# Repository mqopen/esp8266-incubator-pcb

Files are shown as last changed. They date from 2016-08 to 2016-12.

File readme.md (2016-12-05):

# ESP8266 Incubator PCB
Design of ESP8266 incubator PCB.

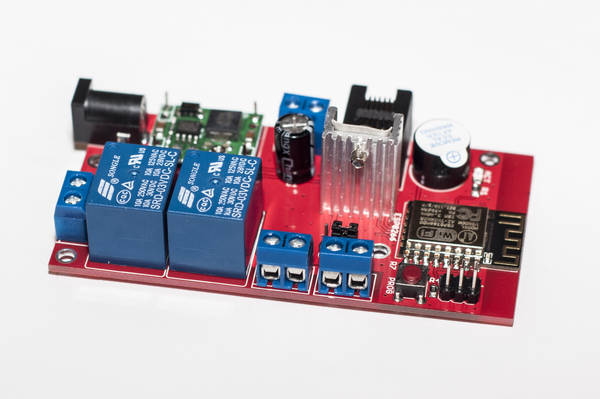
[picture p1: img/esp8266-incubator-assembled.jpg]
Assembled incubator


## Features

  * Powered by mini DC-DC power supply module ([LM2596](http://www.ti.com/lit/ds/symlink/lm2596.pdf) chip).
  * 5.5 mm center positive jack.
  * On-board programming connector.
  * Programming push button.
  * Jumper for enabling power supply module.
  * RJ-11 connector for connecting various sensors.
  * Notification LED.
  * Intended to be manufactured by [dirtypcbs.com](http://dirtypcbs.com/).
  * AVR like ISP header for in circuit programming.
  * Two relays in series for driving heater circuit.
  * Two screw terminals for connecting heaters.
  * 12V screw terminal for controlling fan.
  * Piezo buzzer for alarm signaling.

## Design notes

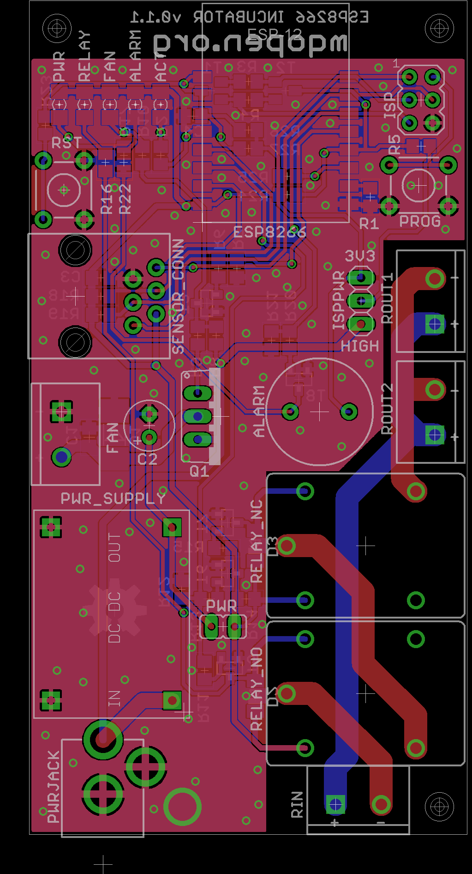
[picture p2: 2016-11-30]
img/board.png

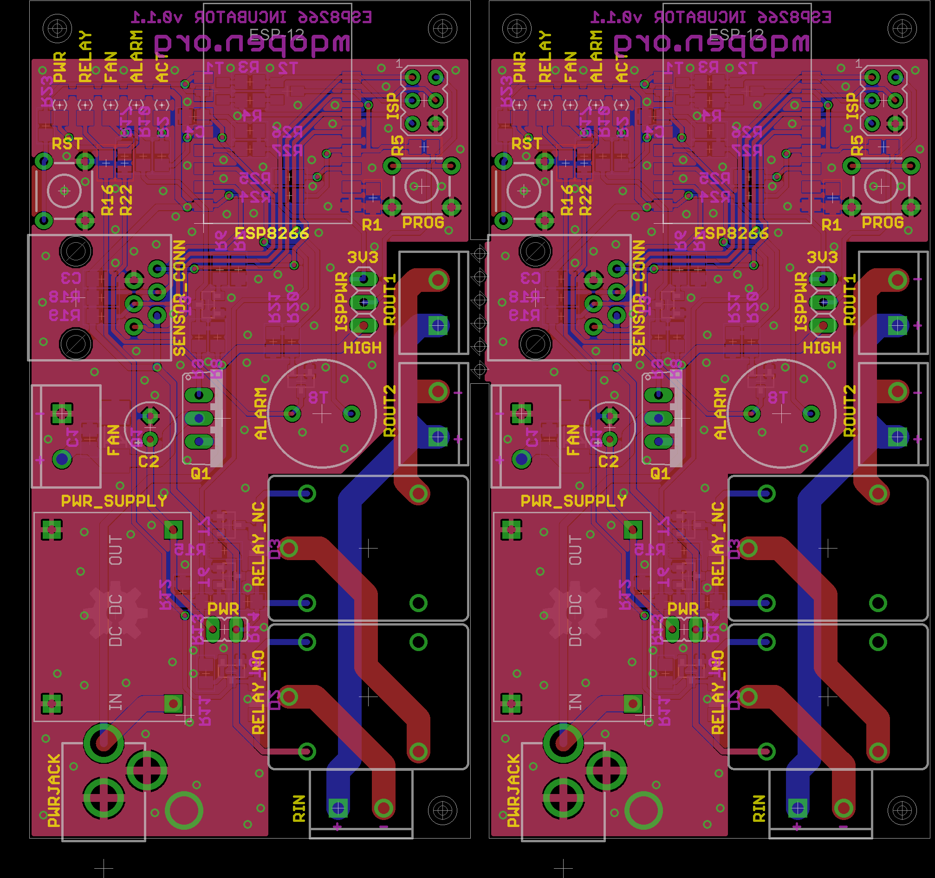
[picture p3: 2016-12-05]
img/board_panelized.png

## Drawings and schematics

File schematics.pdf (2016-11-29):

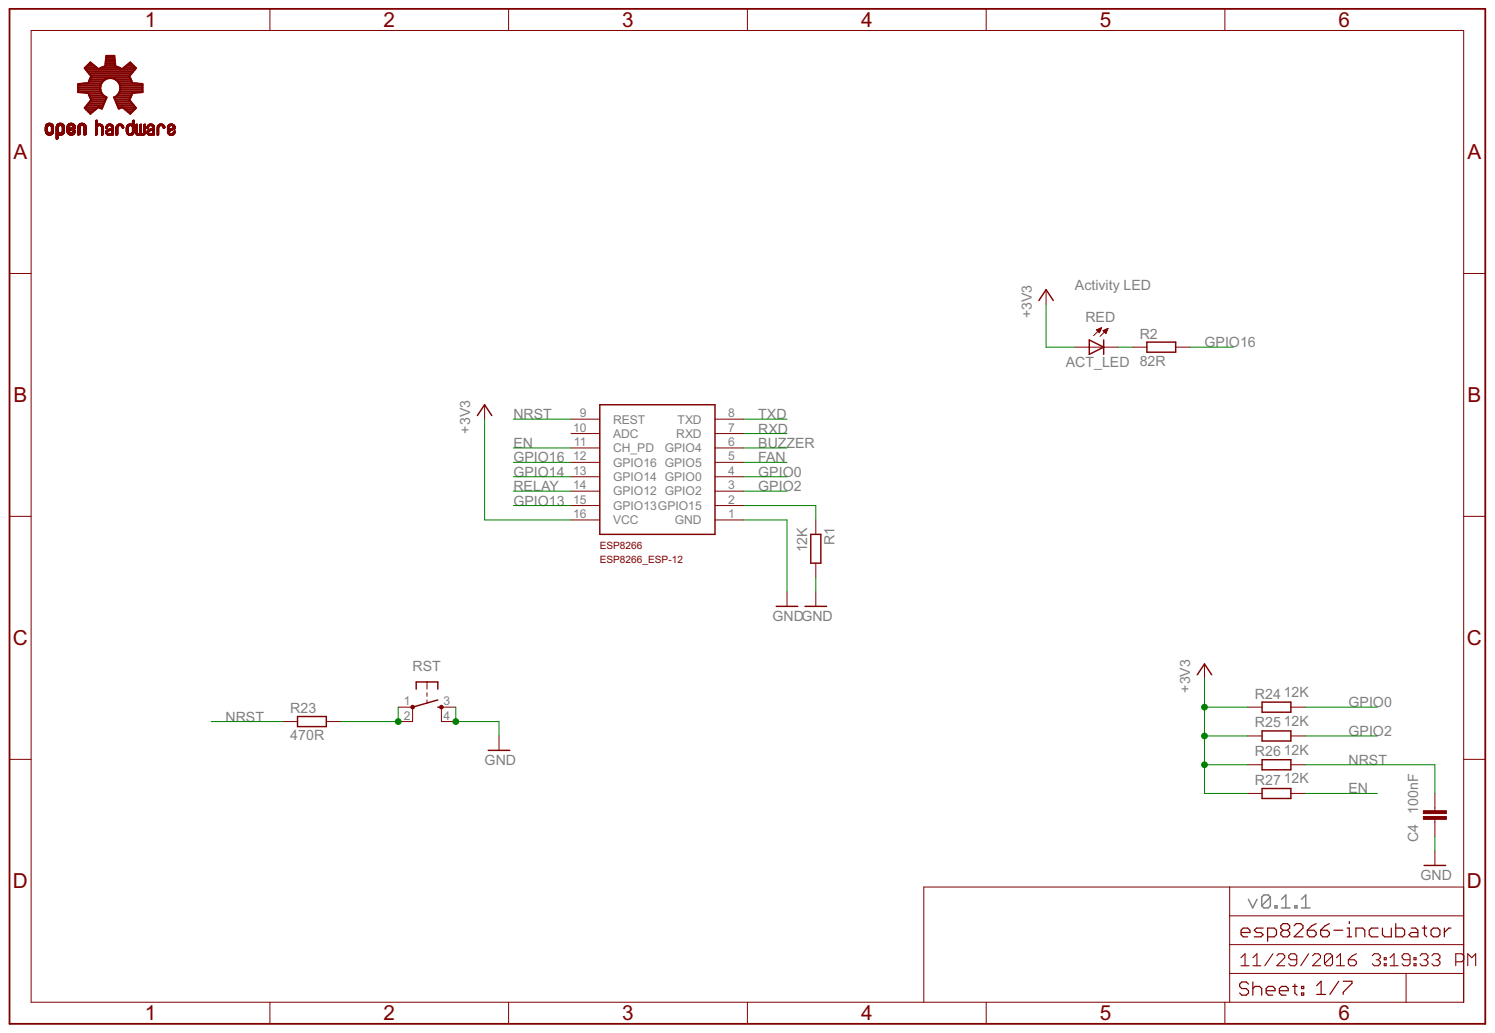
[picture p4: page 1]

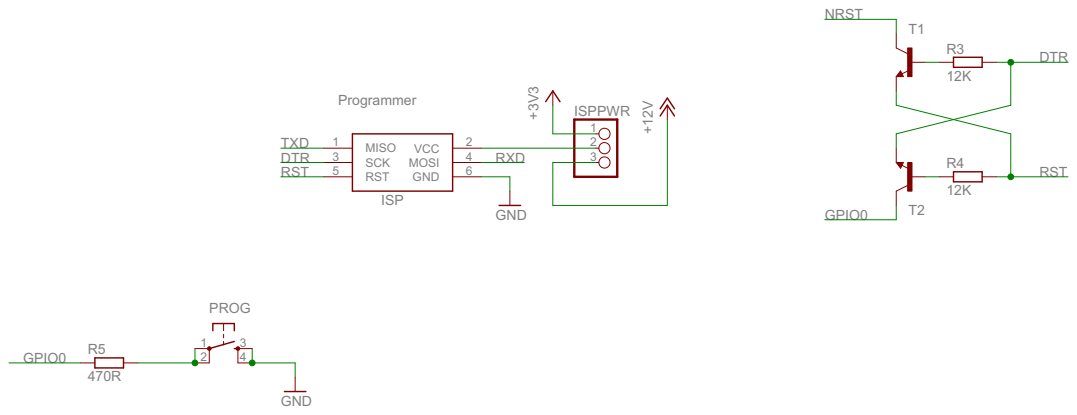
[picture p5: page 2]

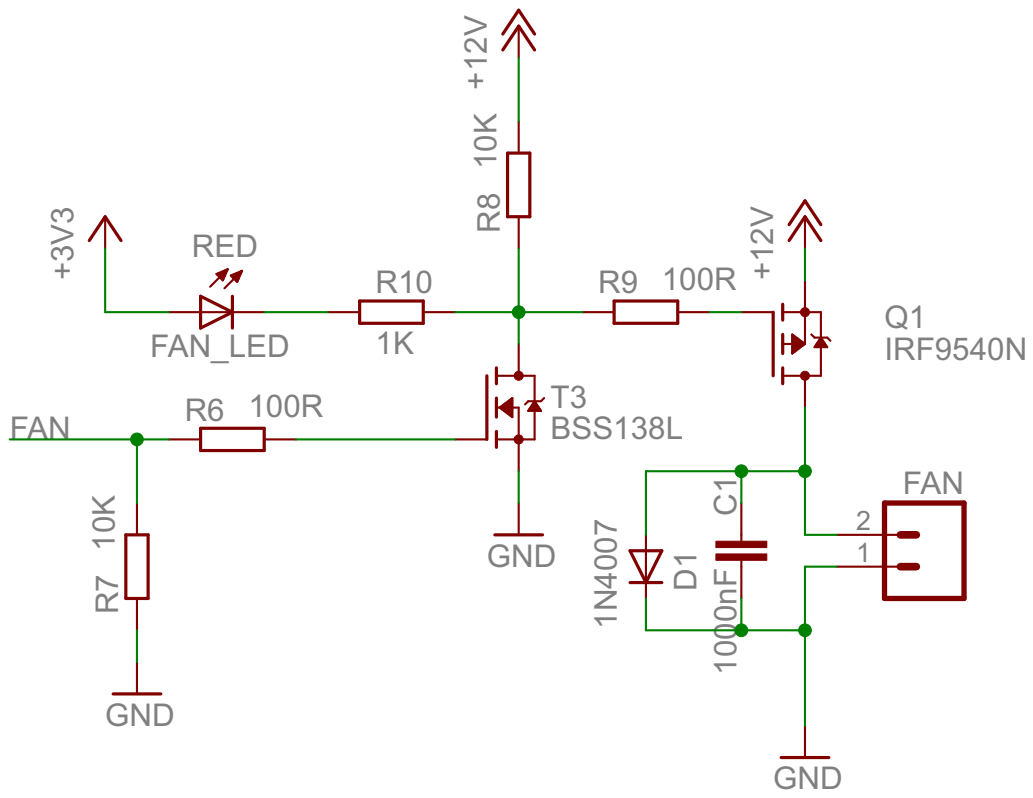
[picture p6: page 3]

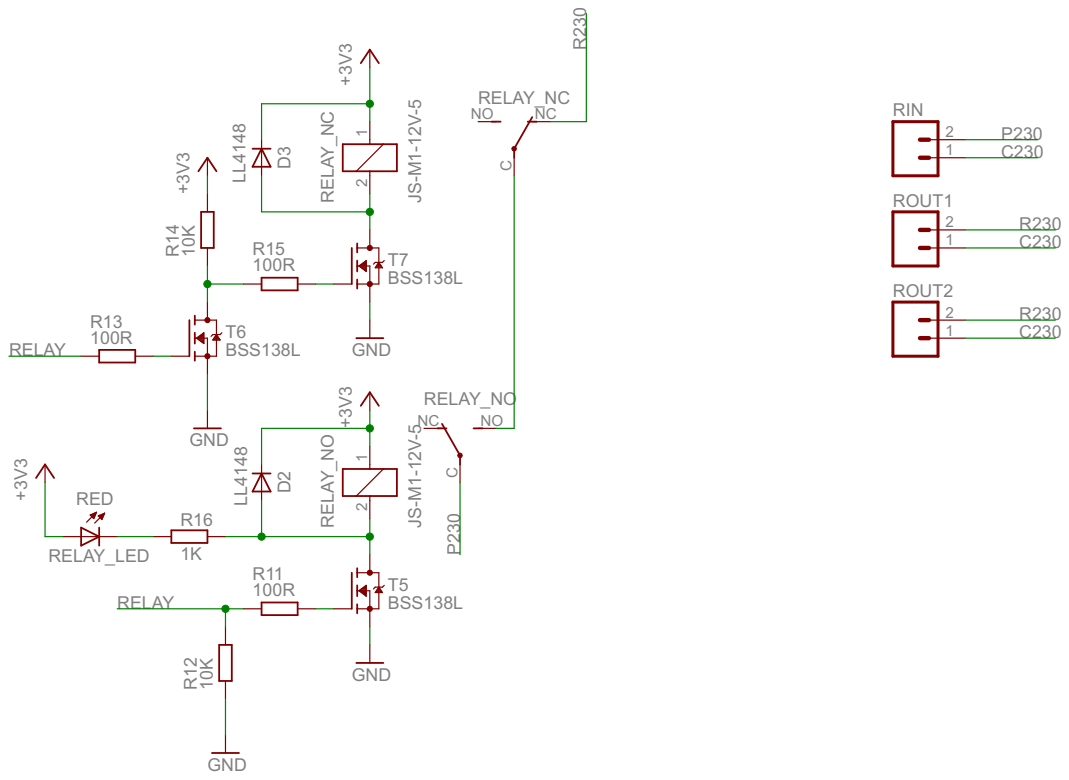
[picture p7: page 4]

JS-M1-12V-5 JS-M1-12V-5 LL4148 LL4148 100R +3V3 GND 100R 100R GND 10K +3V3 GNDBSS138L 10K GNDBSS138L BSS138L +3V3 RED 1K +3V3 2 1 RELAY_NCNO NC C RELAY_NC 2 1 RELAY_NO NC NO C RELAY_NO D2 D3 R13 R15 R11 R14 T5 R12 T6 T7 RELAY_LED R16 RIN 12 ROUT112 ROUT212 R230 R230 R230 P230 P230 RELAY RELAY C230 C230 C230 ABCD 1 2 3 4 5 6 ABCD 1 2 3 4 5 6

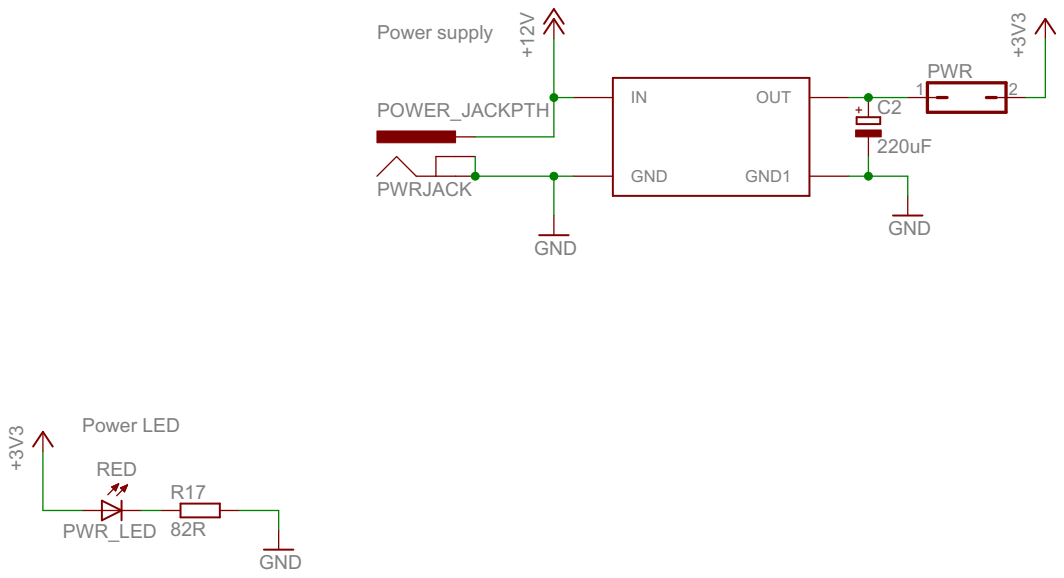
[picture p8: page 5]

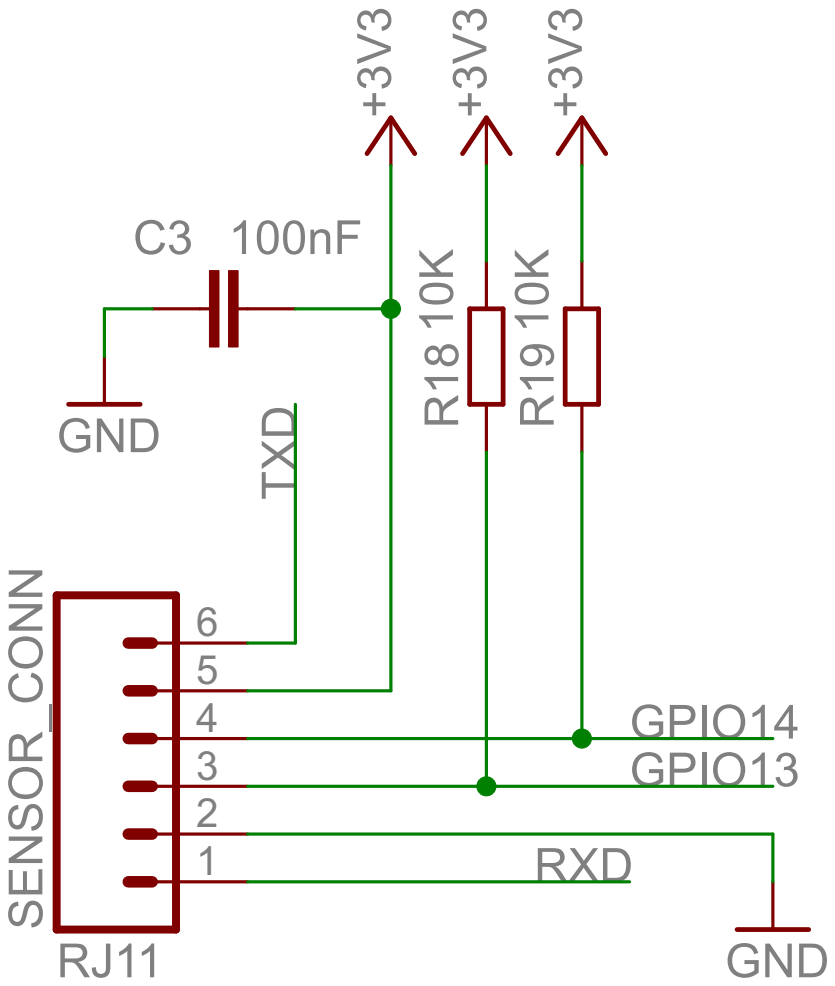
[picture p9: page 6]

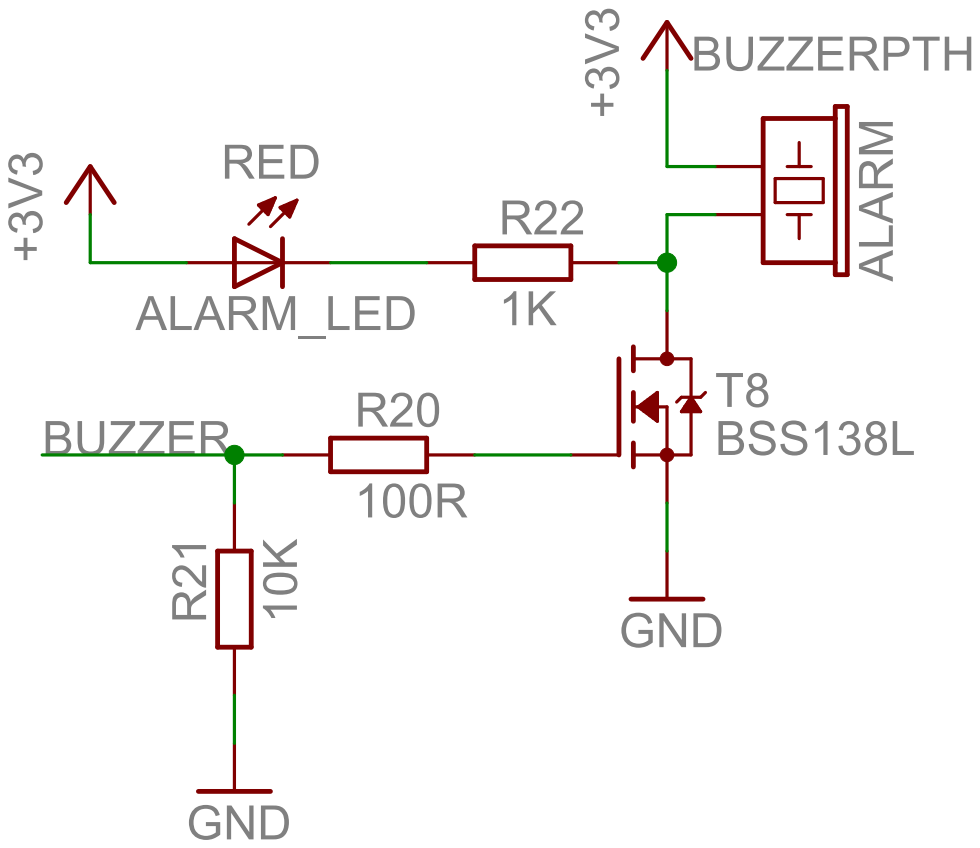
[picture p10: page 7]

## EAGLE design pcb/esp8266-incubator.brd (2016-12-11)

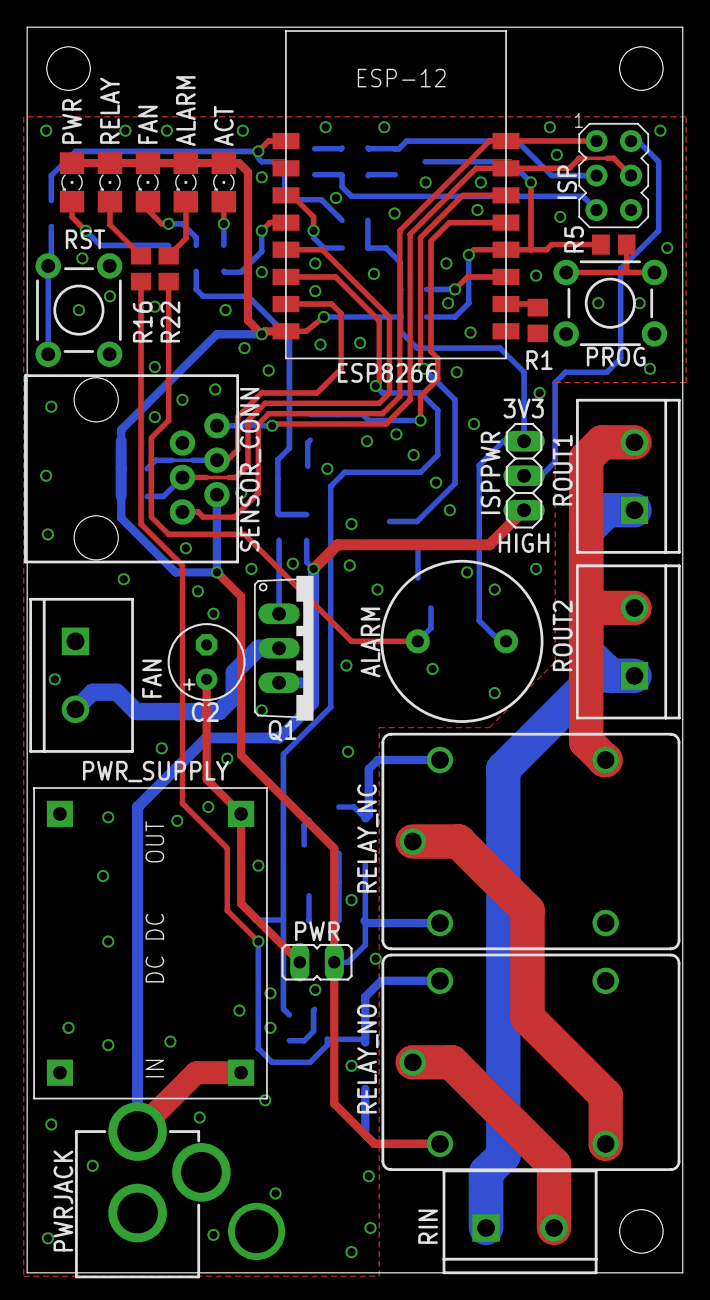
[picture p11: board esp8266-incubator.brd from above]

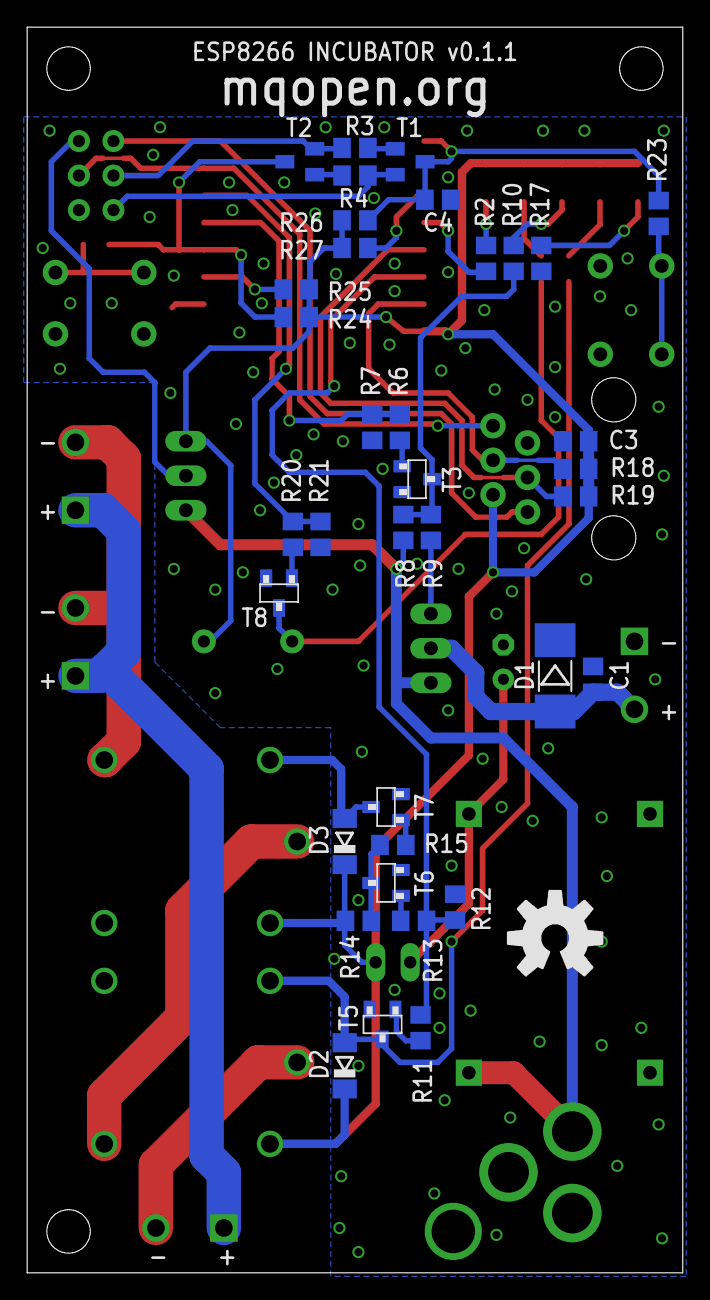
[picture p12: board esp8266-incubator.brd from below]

Board: 2 copper layers, 48.3 x 91.7 mm, 64 parts (37 on the bottom side), 45 nets.

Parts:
ACT_LED: RED; 1206
ALARM: BUZZERPTH; BUZZER-12MM
ALARM_LED: RED; 1206
C1: 1000nF; C0805
C2: 220uF; E2,5-6
C3, C4: 100nF; C0805
D1: 1N4007; MELF-MLL41
D2, D3: LL4148; SOD80C
ESP8266: ESP8266_ESP-12; ESP8266-ESP12
FAN: SCREWTERMINAL-5MM-2
FAN_LED: RED; 1206
ISP: AVRISP-6; AVRISP
ISPPWR: 1X03
PROG: TACTILE-PTH
PWR: JP1
PWRJACK: POWER_JACKPTH; POWER_JACK_PTH
PWR_LED: RED; 1206
PWR_SUPPLY: DC-DC-SMALL; DC-DC
Q1: IRF9540N; TO220V
R1, R3, R4, R7, R8, R12, R14, R18, R19, R21, R24, R25, R26, R27: 10K; R0805
R2, R17: 82R; R0805
R5, R23: 470R; R0805
R6, R9, R11, R13, R15, R20: 100R; R0805
R10, R16, R22: 1K; R0805
RELAY_LED: RED; 1206
RELAY_NC: JS-M1-12V-5; JS-M
RELAY_NO: JS-M1-12V-5; JS-M
RIN: SCREWTERMINAL-5MM-2
ROUT1, ROUT2: SCREWTERMINAL-5MM-2
RST: TACTILE-PTH
SENSOR_CONN: RJ11; RJ11-6
T1, T2: S8050; SOT23-BEC
T3, T5, T6, T7, T8: BSS138L; SOT23
U$1000: OSHW-LOGOL; OSHW-LOGO-L

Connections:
+3V3: ACT_LED.A, ALARM.+, ALARM_LED.A, C3.2, D2.C, D3.C, ESP8266.16, FAN_LED.A, ISPPWR.1, PWR.2, PWR_LED.A, R14.1, R18.2, R19.2, R24.2, R25.2, R26.2, R27.2, RELAY_LED.A, RELAY_NC.1, RELAY_NO.1, SENSOR_CONN.5
+12V: ISPPWR.3, PWRJACK.PWR, PWR_SUPPLY.P$1, Q1.3, R8.1
BUZZER: ESP8266.6, R20.2, R21.1
C230: RIN.1, ROUT1.1, ROUT2.1
DTR: ISP.3, R3.2, T2.E
EN: ESP8266.11, R27.1
FAN: ESP8266.5, R6.2, R7.1
GND: C1.1, C2.-, C3.1, C4.1, D1.C, ESP8266.1, FAN.1, ISP.6, PROG.3, PROG.4, PWRJACK.GND, PWRJACK.GNDBREAK, PWR_SUPPLY.P$3, PWR_SUPPLY.P$4, R1.2, R7.2, R12.2, R17.2, R21.2, RST.3, RST.4, SENSOR_CONN.2, T3.2, T5.2, T6.2, T7.2, T8.2
GPIO0: ESP8266.4, R5.1, R24.1, T2.C
GPIO2: ESP8266.3, R25.1
GPIO13: ESP8266.15, R18.1, SENSOR_CONN.3
GPIO14: ESP8266.13, R19.1, SENSOR_CONN.4
GPIO16: ESP8266.12, R2.2
unnamed: ACT_LED.C, R2.1
unnamed: C2.+, PWR.1, PWR_SUPPLY.P$2
unnamed: R3.1, T1.B
unnamed: PROG.1, PROG.2, R5.2
unnamed: ESP8266.2, R1.1
unnamed: ISP.2, ISPPWR.2
unnamed: R4.1, T2.B
unnamed: R20.1, T8.1
unnamed: D2.A, R16.2, RELAY_NO.2, T5.3
unnamed: R11.1, T5.1
unnamed: R13.1, T6.1
unnamed: R14.2, R15.2, T6.3
unnamed: R15.1, T7.1
unnamed: R16.1, RELAY_LED.C
unnamed: D3.A, RELAY_NC.2, T7.3
unnamed: RELAY_NC.C, RELAY_NO.NO
unnamed: Q1.1, R9.1
unnamed: ALARM_LED.C, R22.1
unnamed: ALARM.-, R22.2, T8.3
unnamed: PWR_LED.C, R17.1
unnamed: FAN_LED.C, R10.1
unnamed: R6.1, T3.1
unnamed: R8.2, R9.2, R10.2, T3.3
unnamed: C1.2, D1.A, FAN.2, Q1.2
unnamed: R23.2, RST.1, RST.2
NRST: C4.2, ESP8266.9, R23.1, R26.1, T1.C
P230: RELAY_NO.C, RIN.2
R230: RELAY_NC.NC, ROUT1.2, ROUT2.2
RELAY: ESP8266.14, R11.2, R12.1, R13.2
RST: ISP.5, R4.2, T1.E
RXD: ESP8266.7, ISP.4, SENSOR_CONN.1
TXD: ESP8266.8, ISP.1, SENSOR_CONN.6

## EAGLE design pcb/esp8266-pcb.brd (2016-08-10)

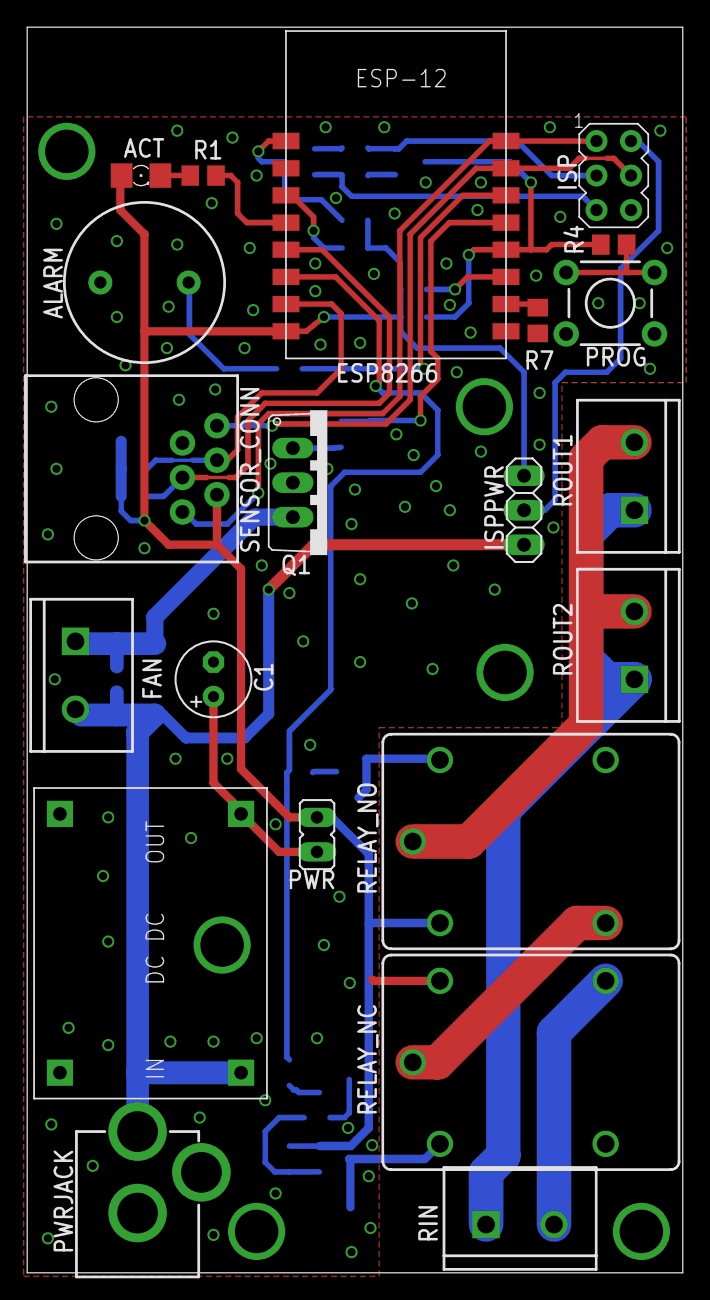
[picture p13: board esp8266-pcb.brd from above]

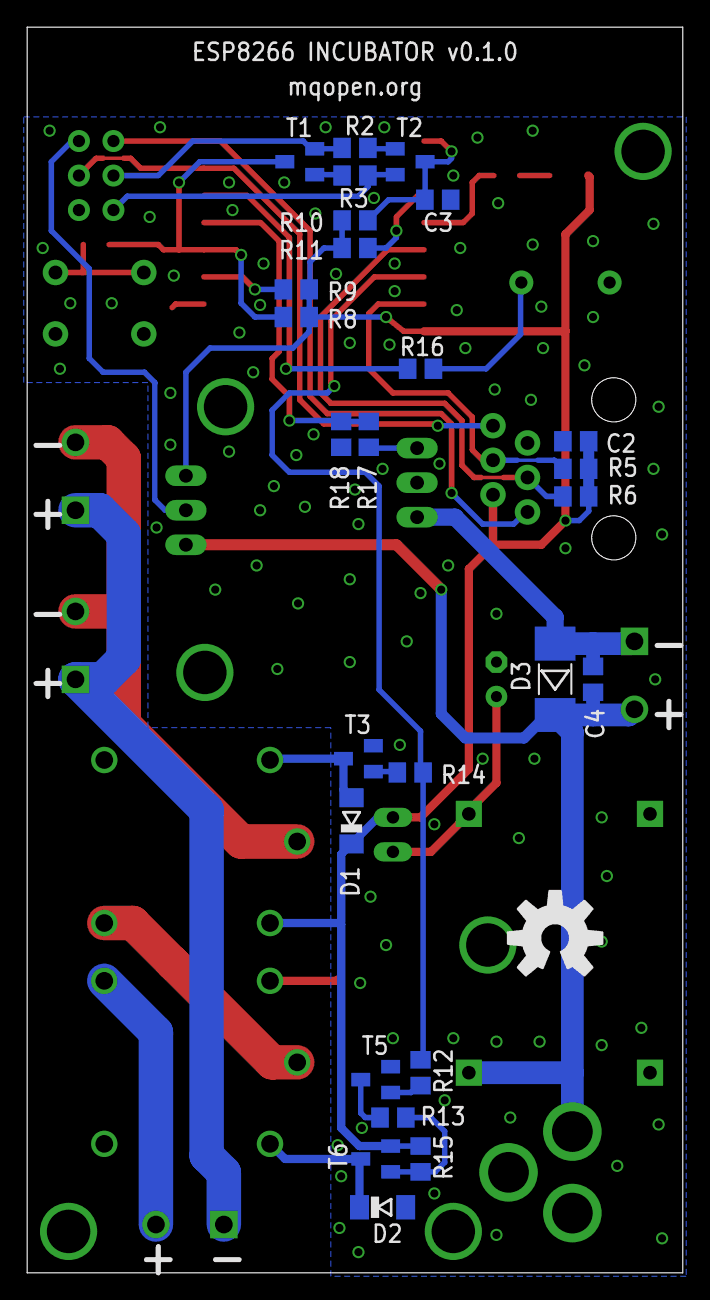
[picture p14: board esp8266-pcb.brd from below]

Board: 2 copper layers, 48.3 x 91.7 mm, 48 parts (27 on the bottom side), 37 nets.

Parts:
ACT: RED; 1206
ALARM: BUZZERPTH; BUZZER-12MM
C1: 220uF; E2,5-6
C2, C3, C4: 100nF; C0805
D1, D2: PMLL4150; SOD80C
D3: MELF-MLL41
ESP8266: ESP8266_ESP-12; ESP8266-ESP12
FAN: SCREWTERMINAL-5MM-2
ISP: AVRISP-6; AVRISP
ISPPWR: 1X03
PROG: TACTILE-PTH
PWR: JP1
PWRJACK: POWER_JACKPTH; POWER_JACK_PTH
Q1: MOSFET-PGDS_TO220V; TO220V
R1: 82R; R0805
R2, R3, R7, R8, R9, R10, R11, R12, R13, R14, R15, R17, R18: 12K; R0805
R4: 470R; R0805
R5, R6: 10K; R0805
R16: 100; R0805
RELAY_NC: JS-M1-12V-5; JS-M
RELAY_NO: JS-M1-12V-5; JS-M
RIN: SCREWTERMINAL-5MM-2
ROUT1, ROUT2: SCREWTERMINAL-5MM-2
SENSOR_CONN: RJ11; RJ11-6
T1, T2, T3, T5, T6: SOT23-BEC
U$1: OSHW-LOGOL; OSHW-LOGO-L
U$2: DC-DC-SMALL; DC-DC

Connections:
+3V3: ACT.A, C2.2, D1.C, ESP8266.16, ISPPWR.1, PWR.2, R5.2, R6.2, R8.2, R9.2, R10.2, R11.2, R15.1, RELAY_NO.1, SENSOR_CONN.5, T6.E
+12V: C4.2, D3.C, FAN.2, ISPPWR.3, PWRJACK.PWR, U$2.P$1
BUZZER: ESP8266.6, R16.2
C230: RIN.1, ROUT1.1, ROUT2.1
DTR: ISP.3, R2.2, T1.E
EN: ESP8266.11, R11.1
FAN: ESP8266.5, R17.2, R18.2
FANOUT: C4.1, D3.A, FAN.1, Q1.3
GND: ALARM.-, C1.-, C2.1, C3.1, D2.A, ESP8266.1, ISP.6, PROG.3, PROG.4, PWRJACK.GND, PWRJACK.GNDBREAK, Q1.2, R7.2, R18.1, RELAY_NC.2, SENSOR_CONN.2, T3.E, T5.E, U$2.P$3, U$2.P$4
GPIO0: ESP8266.4, R4.1, R8.1, T1.C
GPIO2: ESP8266.3, R9.1
GPIO13: ESP8266.15, R5.1, SENSOR_CONN.3
GPIO14: ESP8266.13, R6.1, SENSOR_CONN.4
GPIO16: ESP8266.12, R1.2
unnamed: ACT.C, R1.1
unnamed: C1.+, PWR.1, U$2.P$2
unnamed: R2.1, T2.B
unnamed: PROG.1, PROG.2, R4.2
unnamed: ESP8266.2, R7.1
unnamed: ISP.2, ISPPWR.2
unnamed: R3.1, T1.B
unnamed: ALARM.+, R16.1
unnamed: D1.A, RELAY_NO.2, T3.C
unnamed: R14.1, T3.B
unnamed: R12.1, T5.B
unnamed: R13.2, T5.C
unnamed: R13.1, R15.2, T6.B
unnamed: D2.C, RELAY_NC.1, T6.C
unnamed: RELAY_NC.C, RELAY_NO.NO
unnamed: Q1.1, R17.1
NRST: C3.2, ESP8266.9, R10.1, T2.C
P230: RELAY_NC.NC, RIN.2
R230: RELAY_NO.C, ROUT1.2, ROUT2.2
RELAY: ESP8266.14, R12.2, R14.2
RST: ISP.5, R3.2, T2.E
RXD: ESP8266.7, ISP.4, SENSOR_CONN.1
TXD: ESP8266.8, ISP.1, SENSOR_CONN.6

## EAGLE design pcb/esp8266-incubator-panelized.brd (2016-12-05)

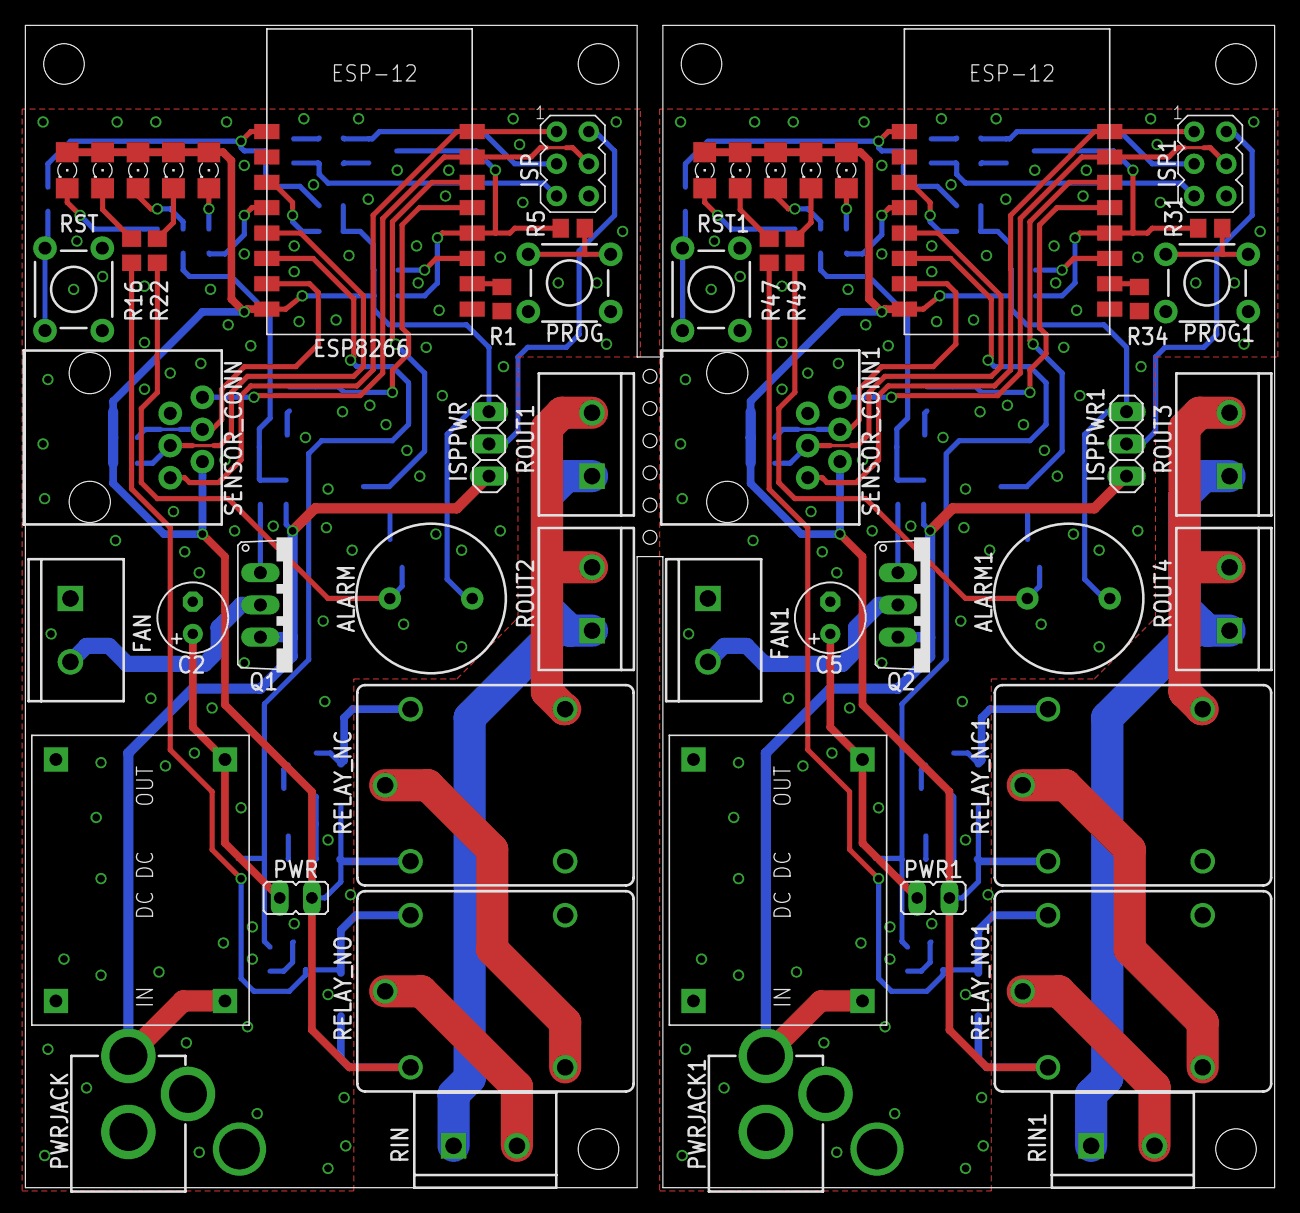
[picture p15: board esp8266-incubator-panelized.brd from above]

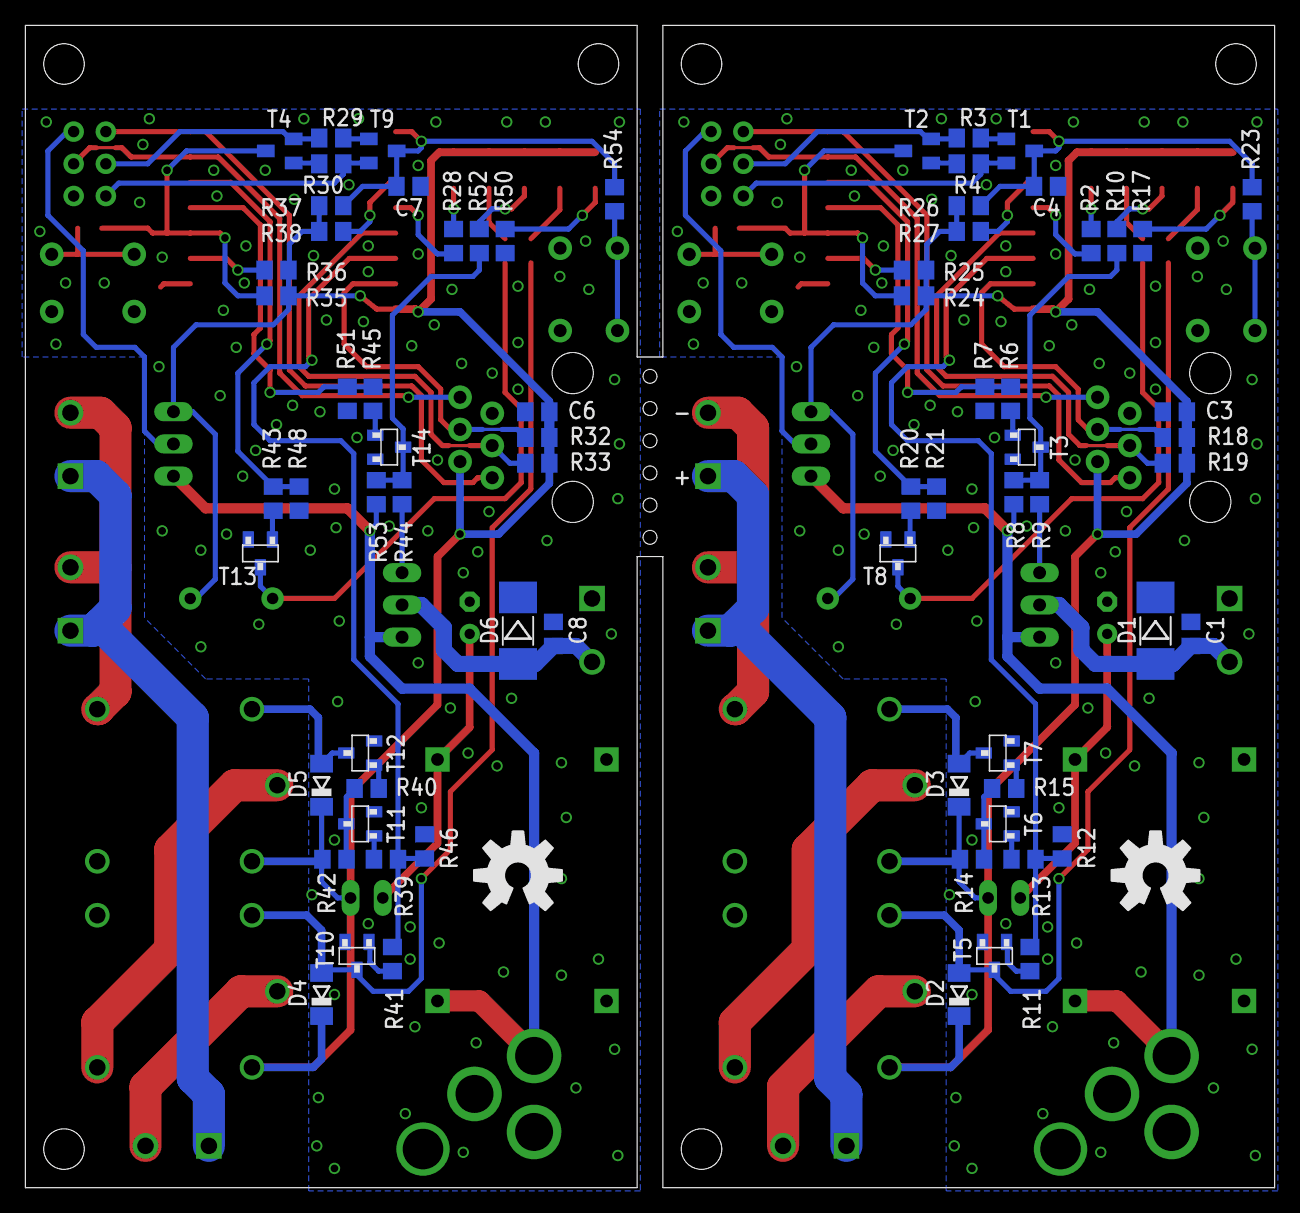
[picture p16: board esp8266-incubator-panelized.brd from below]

Board: 2 copper layers, 98.6 x 91.7 mm, 128 parts (74 on the bottom side), 90 nets.

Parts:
ACT_LED, ACT_LED1: RED; 1206
ALARM, ALARM1: BUZZERPTH; BUZZER-12MM
ALARM_LED, ALARM_LED1: RED; 1206
C1, C8: 1000nF; C0805
C2, C5: 220uF; E2,5-6
C3, C4, C6, C7: 100nF; C0805
D1, D6: 1N4007; MELF-MLL41
D2, D3, D4, D5: LL4148; SOD80C
ESP1, ESP8266: ESP8266_ESP-12; ESP8266-ESP12
FAN, FAN1: SCREWTERMINAL-5MM-2
FAN_LED, FAN_LED1: RED; 1206
ISP, ISP1: AVRISP-6; AVRISP
ISPPWR, ISPPWR1: 1X03
PROG, PROG1: TACTILE-PTH
PWR, PWR1: JP1
PWRJACK, PWRJACK1: POWER_JACKPTH; POWER_JACK_PTH
PWR_LED, PWR_LED1: RED; 1206
PWR_SUPPLY, PWR_SUPPLY1: DC-DC-SMALL; DC-DC
Q1, Q2: IRF9540N; TO220V
R1, R3, R4, R24, R25, R26, R27, R29, R30, R34, R35, R36, R37, R38: 12K; R0805
R2, R17, R28, R50: 82R; R0805
R5, R23, R31, R54: 470R; R0805
R6, R9, R11, R13, R15, R20, R39, R40, R41, R43, R44, R45: 100R; R0805
R7, R8, R12, R14, R18, R19, R21, R32, R33, R42, R46, R48, R51, R53: 10K; R0805
R10, R16, R22, R47, R49, R52: 1K; R0805
RELAY_LED, RELAY_LED1: RED; 1206
RELAY_NC, RELAY_NC1: JS-M1-12V-5; JS-M
RELAY_NO, RELAY_NO1: JS-M1-12V-5; JS-M
RIN, RIN1: SCREWTERMINAL-5MM-2
ROUT1, ROUT2, ROUT3, ROUT4: SCREWTERMINAL-5MM-2
RST, RST1: TACTILE-PTH
SENSOR_CONN, SENSOR_CONN1: RJ11; RJ11-6
T1, T2, T4, T9: S8050; SOT23-BEC
T3, T5, T6, T7, T8, T10, T11, T12, T13, T14: BSS138L; SOT23
U$1, U$1000: OSHW-LOGOL; OSHW-LOGO-L

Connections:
+3V1: ACT_LED1.A, ALARM1.+, ALARM_LED1.A, C6.2, D4.C, D5.C, ESP1.16, FAN_LED1.A, ISPPWR1.1, PWR1.2, PWR_LED1.A, R32.2, R33.2, R35.2, R36.2, R37.2, R38.2, R42.1, RELAY_LED1.A, RELAY_NC1.1, RELAY_NO1.1, SENSOR_CONN1.5
+3V3: ACT_LED.A, ALARM.+, ALARM_LED.A, C3.2, D2.C, D3.C, ESP8266.16, FAN_LED.A, ISPPWR.1, PWR.2, PWR_LED.A, R14.1, R18.2, R19.2, R24.2, R25.2, R26.2, R27.2, RELAY_LED.A, RELAY_NC.1, RELAY_NO.1, SENSOR_CONN.5
+12V: ISPPWR.3, PWRJACK.PWR, PWR_SUPPLY.P$1, Q1.3, R8.1
+12V1: ISPPWR1.3, PWRJACK1.PWR, PWR_SUPPLY1.P$1, Q2.3, R53.1
BUZZER: ESP8266.6, R20.2, R21.1
BUZZER1: ESP1.6, R43.2, R48.1
C1: RIN1.1, ROUT3.1, ROUT4.1
C230: RIN.1, ROUT1.1, ROUT2.1
DTR: ISP.3, R3.2, T2.E
DTR1: ISP1.3, R29.2, T4.E
EN: ESP8266.11, R27.1
EN1: ESP1.11, R38.1
FAN: ESP8266.5, R6.2, R7.1
FAN1: ESP1.5, R45.2, R51.1
GND: C1.1, C2.-, C3.1, C4.1, D1.C, ESP8266.1, FAN.1, ISP.6, PROG.3, PROG.4, PWRJACK.GND, PWRJACK.GNDBREAK, PWR_SUPPLY.P$3, PWR_SUPPLY.P$4, R1.2, R7.2, R12.2, R17.2, R21.2, RST.3, RST.4, SENSOR_CONN.2, T3.2, T5.2, T6.2, T7.2, T8.2
GND1: C5.-, C6.1, C7.1, C8.1, D6.C, ESP1.1, FAN1.1, ISP1.6, PROG1.3, PROG1.4, PWRJACK1.GND, PWRJACK1.GNDBREAK, PWR_SUPPLY1.P$3, PWR_SUPPLY1.P$4, R34.2, R46.2, R48.2, R50.2, R51.2, RST1.3, RST1.4, SENSOR_CONN1.2, T10.2, T11.2, T12.2, T13.2, T14.2
GPIO0: ESP8266.4, R5.1, R24.1, T2.C
GPIO1: ESP1.4, R31.1, R35.1, T4.C
GPIO2: ESP8266.3, R25.1
GPIO3: ESP1.12, R28.2
GPIO4: ESP1.13, R33.1, SENSOR_CONN1.4
GPIO5: ESP1.15, R32.1, SENSOR_CONN1.3
GPIO6: ESP1.3, R36.1
GPIO13: ESP8266.15, R18.1, SENSOR_CONN.3
GPIO14: ESP8266.13, R19.1, SENSOR_CONN.4
GPIO16: ESP8266.12, R2.2
unnamed: ACT_LED.C, R2.1
unnamed: C2.+, PWR.1, PWR_SUPPLY.P$2
unnamed: R3.1, T1.B
unnamed: PROG.1, PROG.2, R5.2
unnamed: ESP8266.2, R1.1
unnamed: ISP.2, ISPPWR.2
unnamed: R4.1, T2.B
unnamed: R20.1, T8.1
unnamed: D2.A, R16.2, RELAY_NO.2, T5.3
unnamed: ACT_LED1.C, R28.1
unnamed: R11.1, T5.1
unnamed: R13.1, T6.1
unnamed: R14.2, R15.2, T6.3
unnamed: R15.1, T7.1
unnamed: R16.1, RELAY_LED.C
unnamed: D3.A, RELAY_NC.2, T7.3
unnamed: RELAY_NC.C, RELAY_NO.NO
unnamed: Q1.1, R9.1
unnamed: ALARM_LED.C, R22.1
unnamed: ALARM.-, R22.2, T8.3
unnamed: PWR_LED.C, R17.1
unnamed: FAN_LED.C, R10.1
unnamed: R6.1, T3.1
unnamed: R8.2, R9.2, R10.2, T3.3
unnamed: C1.2, D1.A, FAN.2, Q1.2
unnamed: R23.2, RST.1, RST.2
unnamed: R29.1, T9.B
unnamed: R30.1, T4.B
unnamed: PROG1.1, PROG1.2, R31.2
unnamed: C5.+, PWR1.1, PWR_SUPPLY1.P$2
unnamed: ESP1.2, R34.1
unnamed: ISP1.2, ISPPWR1.2
unnamed: R41.1, T10.1
unnamed: D4.A, R47.2, RELAY_NO1.2, T10.3
unnamed: R39.1, T11.1
unnamed: R40.2, R42.2, T11.3
unnamed: R40.1, T12.1
unnamed: RELAY_NC1.C, RELAY_NO1.NO
unnamed: Q2.1, R44.1
unnamed: D5.A, RELAY_NC1.2, T12.3
unnamed: R47.1, RELAY_LED1.C
unnamed: R43.1, T13.1
unnamed: ALARM_LED1.C, R49.1
unnamed: ALARM1.-, R49.2, T13.3
unnamed: PWR_LED1.C, R50.1
unnamed: R45.1, T14.1
unnamed: FAN_LED1.C, R52.1
unnamed: R44.2, R52.2, R53.2, T14.3
unnamed: C8.2, D6.A, FAN1.2, Q2.2
unnamed: R54.2, RST1.1, RST1.2
NRST: C4.2, ESP8266.9, R23.1, R26.1, T1.C
NRST1: C7.2, ESP1.9, R37.1, R54.1, T9.C
P1: RELAY_NO1.C, RIN1.2
P230: RELAY_NO.C, RIN.2
R1: RELAY_NC1.NC, ROUT3.2, ROUT4.2
R230: RELAY_NC.NC, ROUT1.2, ROUT2.2
RELAY: ESP8266.14, R11.2, R12.1, R13.2
RELAY1: ESP1.14, R39.2, R41.2, R46.1
RST: ISP.5, R4.2, T1.E
RST1: ISP1.5, R30.2, T9.E
RXD: ESP8266.7, ISP.4, SENSOR_CONN.1
RXD1: ESP1.7, ISP1.4, SENSOR_CONN1.1
TXD: ESP8266.8, ISP.1, SENSOR_CONN.6
TXD1: ESP1.8, ISP1.1, SENSOR_CONN1.6

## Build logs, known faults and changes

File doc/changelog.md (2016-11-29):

# ESP8266 Incubator changelog

## v0.1.0

 - First board design.
 - Intended to be manufactured by [dirtypcbs.com](http://dirtypcbs.com/).
 - Powered by mini DC-DC power supply module ([LM2596](http://www.ti.com/lit/ds/symlink/lm2596.pdf) chip).
 - 5.5 mm center positive jack.
 - On-board programming connector.
 - Programming push button.
 - Jumper for enabling power supply module.
 - SMD notification LED.
 - Two relays in series for driving heater circuit.
 - Two screw terminals for connecting heaters.
 - 12V screw terminal for controlling fan.
 - Piezo buzzer for alarm signaling.

## v0.1.1

 - Schematics splited into multiple sheets.
 - Added PWR_LED.
 - Alarm buzzer is switched using N-MOSFET.
 - Added ALARM_LED.
 - Relays are controlled using MOSFET.
 - Fixed logic of RELAY_NC.
 - Added RELAY_LED.
 - Fan is controlled using N-CHANNEL and P-CHANNEL MOSFETS.
 - Added FAN_LED.
 - Added RST button.

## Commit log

2016-08-10 Initial commit.
    [esp8266-pcb.brd, esp8266-pcb.sch]
2016-11-28 Renamed source files.
    [esp8266-incubator.brd, esp8266-incubator.sch]
2016-11-28 Added schematics PDF file.
2016-11-28 Added readme file and assembled board image.
2016-11-29 Designed new version schematics and board design.
    [esp8266-incubator.brd, esp8266-incubator.sch]
2016-11-29 Added version number to all schematics sheets.
    [esp8266-incubator.sch]
2016-11-29 Updated schematics PDF file.
2016-11-29 Fixed schematics PDF file.
2016-11-30 Updated LED labels.
    [esp8266-incubator.brd]
2016-11-30 Added board image.
2016-11-30 Updated relay trace.
    [esp8266-incubator.brd]
2016-11-30 Updated mounting holes.
    [esp8266-incubator.brd]
2016-11-30 Design update.
    [esp8266-incubator.brd, esp8266-incubator.sch]
2016-12-05 Added panelized board design.
    [esp8266-incubator-panelized.brd]
2016-12-05 Updated .gitignore file. Removed ignore of gerber files.
2016-12-05 Added GERBER files.
    [esp8266-incubator-panelized.GBL, esp8266-incubator-panelized.GBO, esp8266-incubator-panelized.GBP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]
2016-12-05 Added panelized board image.
2016-12-05 Hiden names layers.
    [esp8266-incubator-panelized.brd]
2016-12-11 Updated some resistor values.
    [esp8266-incubator.brd, esp8266-incubator.sch]

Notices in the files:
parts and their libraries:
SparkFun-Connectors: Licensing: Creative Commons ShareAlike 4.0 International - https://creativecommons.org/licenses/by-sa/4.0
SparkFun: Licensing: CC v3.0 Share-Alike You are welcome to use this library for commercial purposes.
